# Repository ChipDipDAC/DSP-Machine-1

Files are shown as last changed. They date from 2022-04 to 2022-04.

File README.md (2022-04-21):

# DSP-Machine-1
Hi-Res Streamer - Power Amplifier for Raspberry Pi<br>
<a class="link" href="https://www.chipdip.ru/catalog-show/for-you-projects?p.0=ChipDipDac"><strong>DSP Machine 1</strong></a> - cтример, цифроаналоговый преобразователь ЦАП, аудиопроцессор, усилитель для микрокомпьютеров Raspberry Pi.<br />
Для построения стримера-усилителя вы можете использовать любой микрокомпьютер Raspberry Pi 2 или 3. Микрокомпьютер устанавливается на 40-пиновый разъем аудио карты. В качестве ПО используйте любой плеер или ОС образ, которых записан на микроSD карточку для Raspberry Pi. Операционные системы автоматически определяют аудиокарту ChipDip DAC и настраивают вывод звука именно на неё. В некоторых плеерах может понадобится выбрать в качестве устройства вывода звука - ChipDip DAC.<br />
<br />
- Plug and Play не требует пайки<br />
- Совместим с Raspberry Pi<br />
- Официальная поддержка RaspberryPi OS / Volumio3 / rAudio1 / Album Player / OpenELEC / Manjaro OS / MoOde и другими<br />
- DSP ADAU1701, чип усилителя TPA3255 для наилучшего качества звука.<br />
- Мощность 2х60 Вт<br />
- Разъемы аудиовыхода: две пары винтовых клемм (левый и правый)<br />
- Встроенная EEPROM для автоматической настройки ОС (с защитой от записи).<br />
- Автоматическое переключение частот в соответствии с входными сигналами I2S.<br />
- Диапазон частот дискретизации и разрядности от 44,1кГц/16 бит до 192кГц/32 бит<br />
- Совместим с ПО SigmaStudio и ChipStudio для перестройки аудиопроцессора<br />
<br />
Задать вопросы можно на форуме в разделе <a class="link" href="https://forum.chipdip.ru/index.php#chipdip-dac.39">ChipDip DAC</a>
<p><a class="galery" href="https://static.chipdip.ru/lib/992/DOC015992500.jpg">Pins DSP Machine1</a></p>

<p><a class="galery" href="https://static.chipdip.ru/lib/992/DOC015992501.jpg">Pins DSP Machine1</a></p>

<h2>Что под крышкой *</h2>

<p><a class="galery" href="https://static.chipdip.ru/lib/992/DOC015992815.jpg">Pins DSP Machine1</a></p>

<p><a class="galery" href="https://static.chipdip.ru/lib/992/DOC015992816.jpg">Pins DSP Machine1</a></p>
* Микрокомпьютер Raspberry Pi в комплект не входит.

<h2>Сравнительная таблица</h2>

<table class="user_t">
	<tbody>
		<tr>
			<td class="tcenter">&nbsp;</td>
			<td class="tcenter">DSP Machine 1</td>
			<td class="tcenter">DSP Machine 2</td>
			<td class="tcenter">DSP Machine 3</td>
		</tr>
		<tr>
			<td class="tcenter">Темброблок</td>
			<td class="tcenter">+</td>
			<td class="tcenter">+</td>
			<td class="tcenter">+</td>
		</tr>
		<tr>
			<td class="tcenter">SuperBass</td>
			<td class="tcenter">+</td>
			<td class="tcenter">+</td>
			<td class="tcenter">+</td>
		</tr>
		<tr>
			<td class="tcenter">Mute</td>
			<td class="tcenter">+</td>
			<td class="tcenter">+</td>
			<td class="tcenter">+</td>
		</tr>
		<tr>
			<td class="tcenter">Блок питания</td>
			<td class="tcenter">+</td>
			<td class="tcenter">+</td>
			<td class="tcenter">+</td>
		</tr>
		<tr>
			<td class="tcenter">Корректное выключение</td>
			<td class="tcenter">+</td>
			<td class="tcenter">+</td>
			<td class="tcenter">+</td>
		</tr>
		<tr>
			<td class="tcenter">Линейный выход</td>
			<td class="tcenter">-</td>
			<td class="tcenter">+</td>
			<td class="tcenter">+</td>
		</tr>
		<tr>
			<td class="tcenter">Усилитель мощности</td>
			<td class="tcenter">+</td>
			<td class="tcenter">-</td>
			<td class="tcenter">-</td>
		</tr>
		<tr>
			<td class="tcenter">Выход SPDIF</td>
			<td class="tcenter">-</td>
			<td class="tcenter">-</td>
			<td class="tcenter">+</td>
		</tr>
		<tr>
			<td class="tcenter">Выход Toslink</td>
			<td class="tcenter">-</td>
			<td class="tcenter">-</td>
			<td class="tcenter">+</td>
		</tr>
		<tr>
			<td class="tcenter">SigmaStudio</td>
			<td class="tcenter">+</td>
			<td class="tcenter">-</td>
			<td class="tcenter">+</td>
		</tr>
		<tr>
			<td class="tcenter">PurePathStudio</td>
			<td class="tcenter">-</td>
			<td class="tcenter">+</td>
			<td class="tcenter">-</td>
		</tr>
		<tr>
			<td class="tcenter">ChipStudio</td>
			<td class="tcenter">+</td>
			<td class="tcenter">+</td>
			<td class="tcenter">+</td>
		</tr>
	</tbody>
</table>
<br />

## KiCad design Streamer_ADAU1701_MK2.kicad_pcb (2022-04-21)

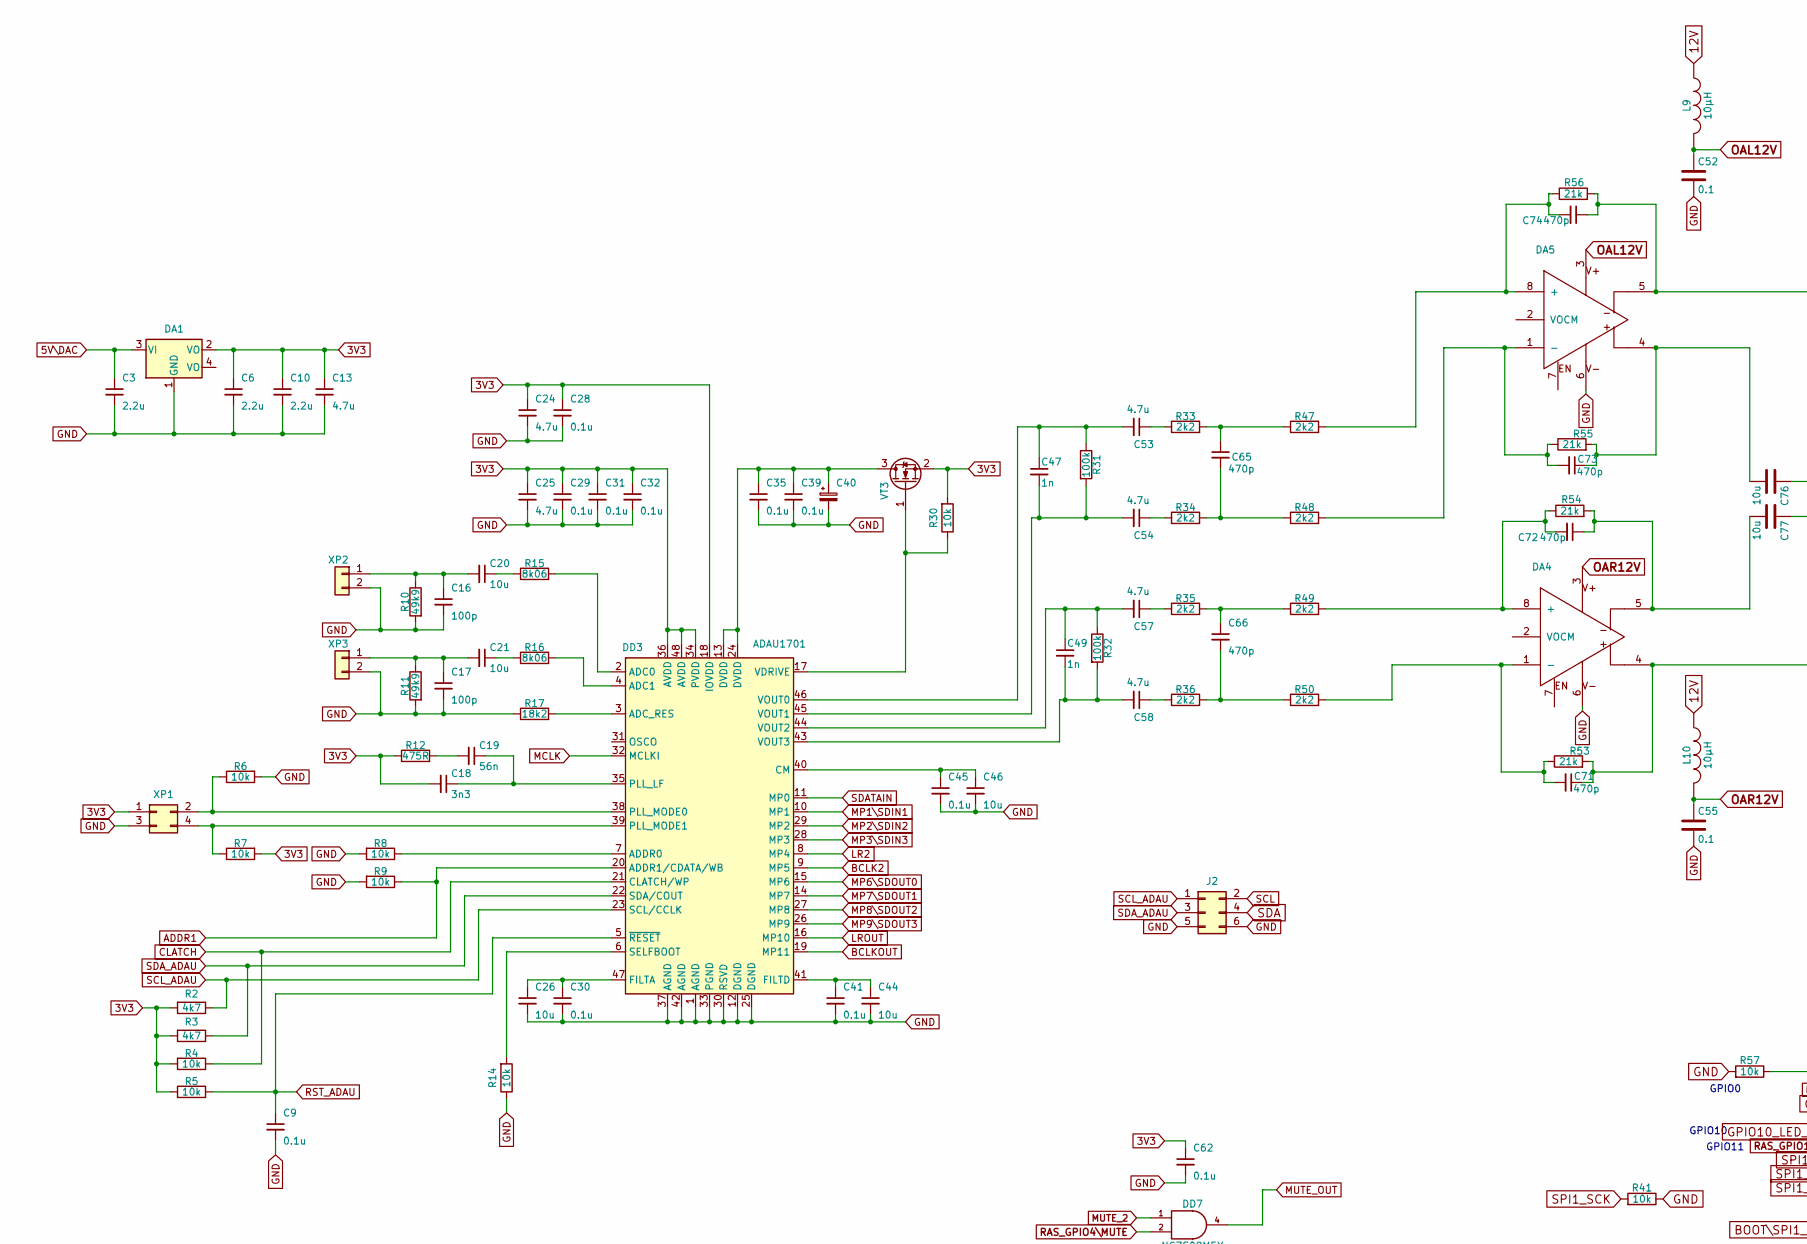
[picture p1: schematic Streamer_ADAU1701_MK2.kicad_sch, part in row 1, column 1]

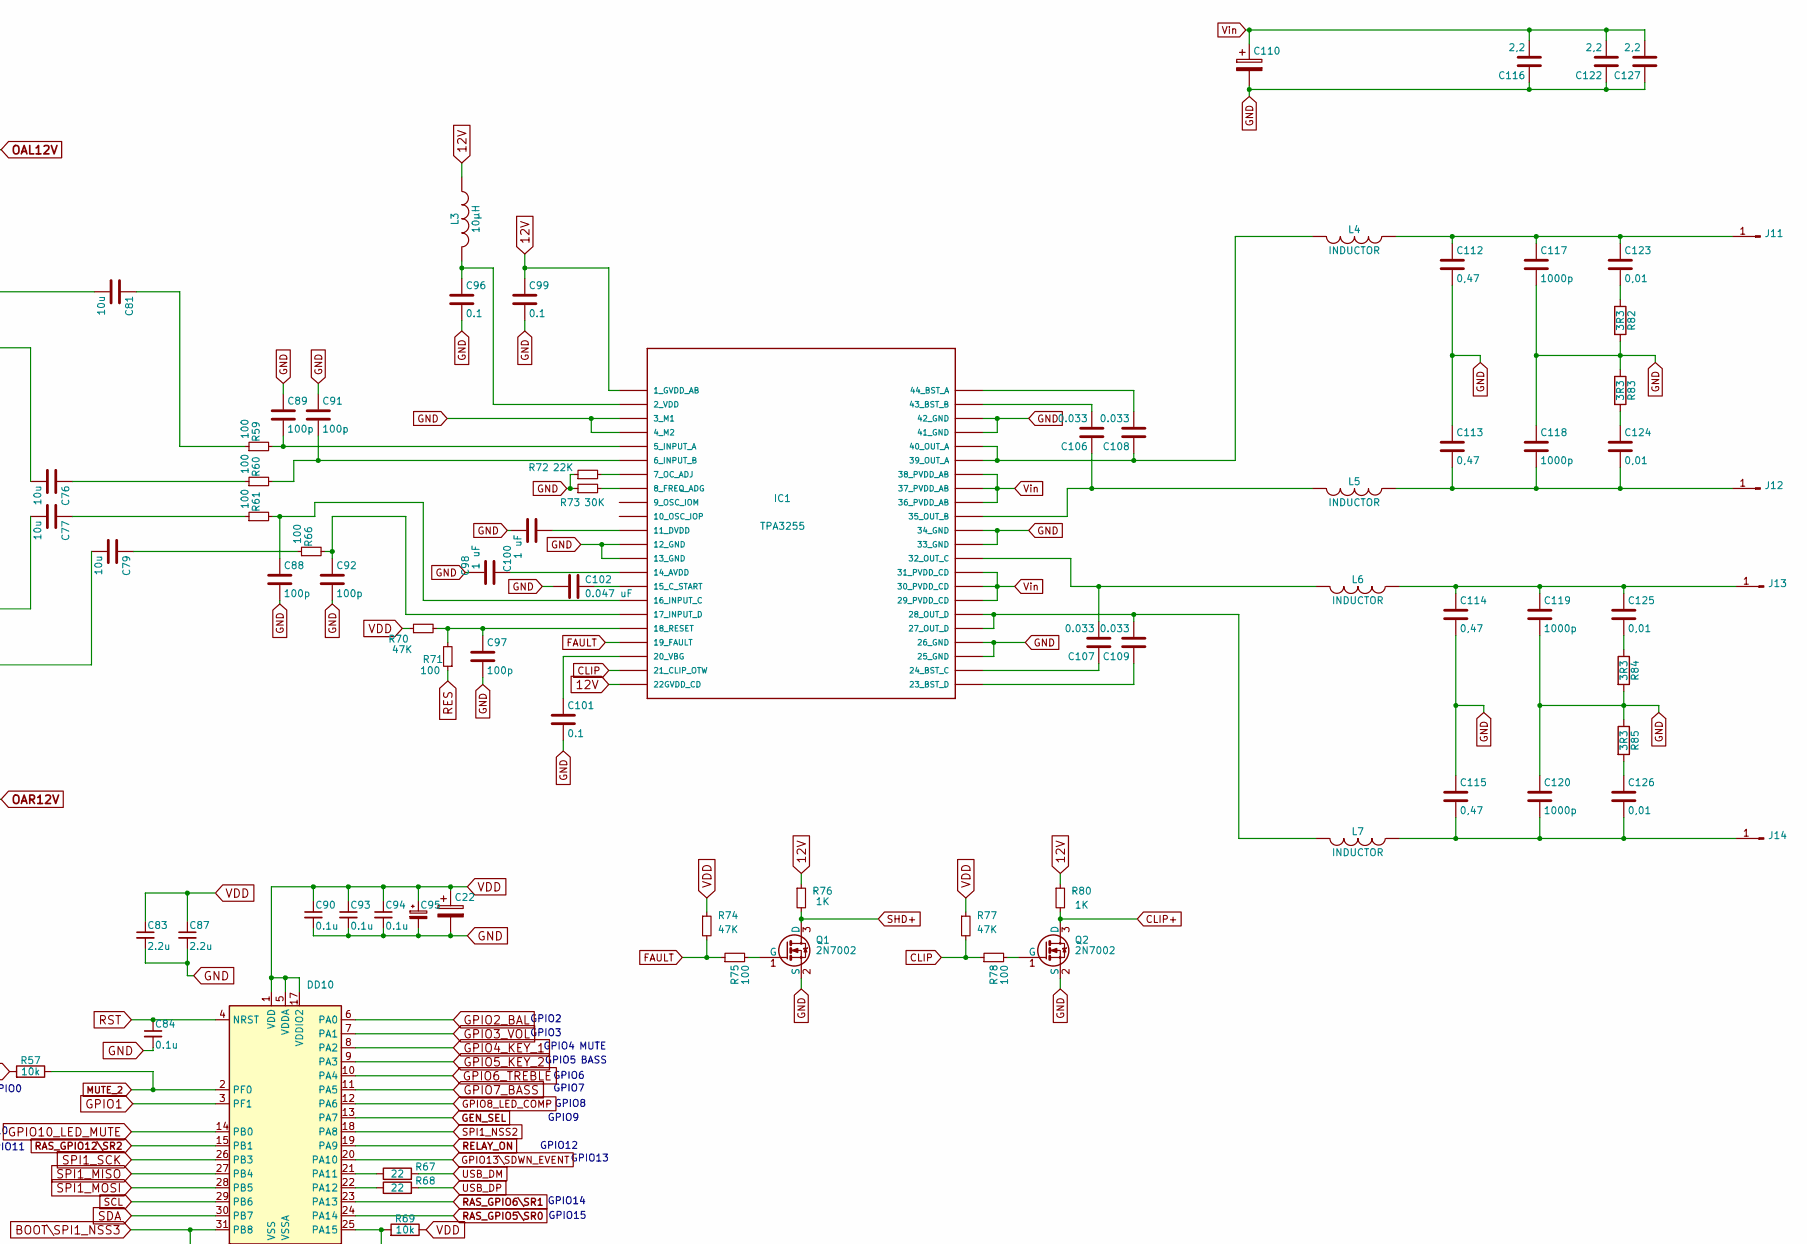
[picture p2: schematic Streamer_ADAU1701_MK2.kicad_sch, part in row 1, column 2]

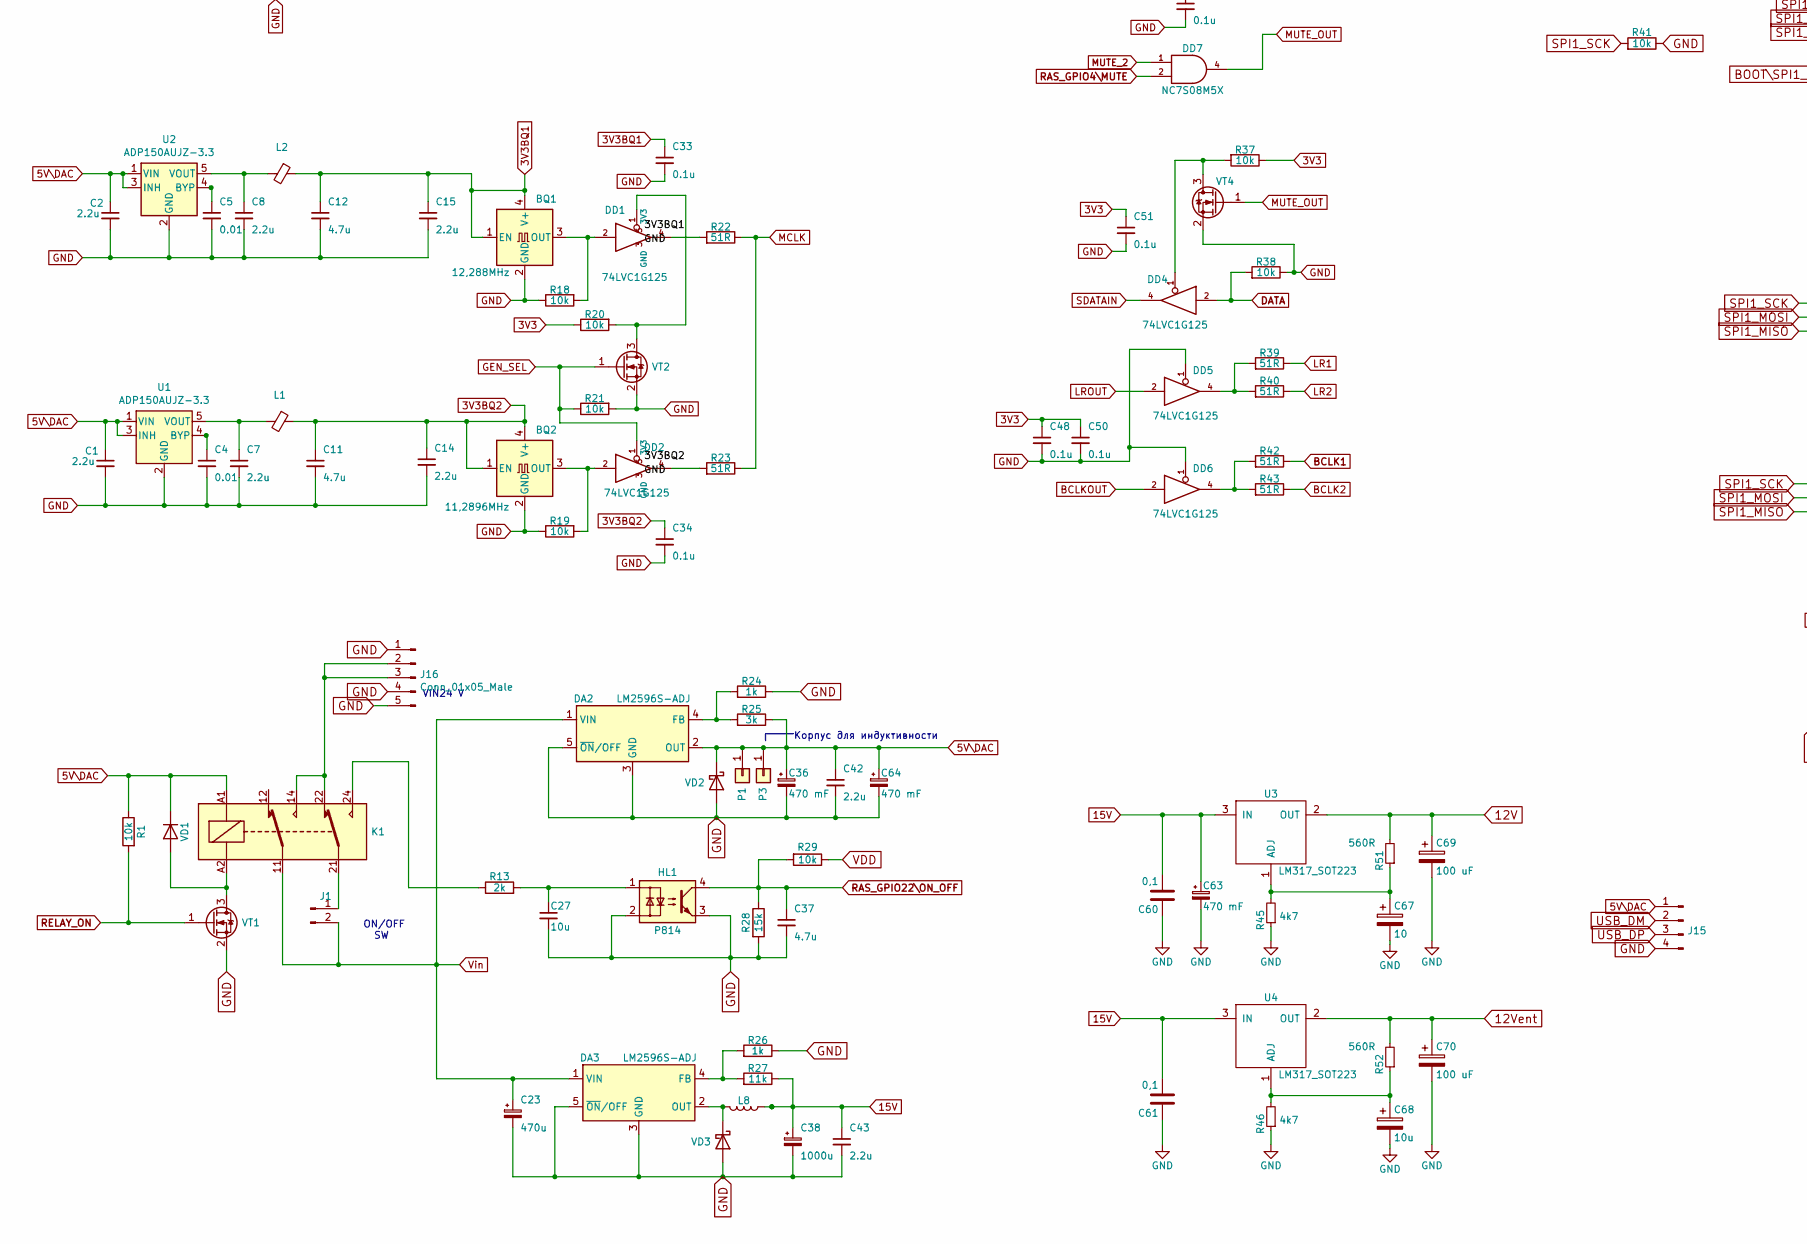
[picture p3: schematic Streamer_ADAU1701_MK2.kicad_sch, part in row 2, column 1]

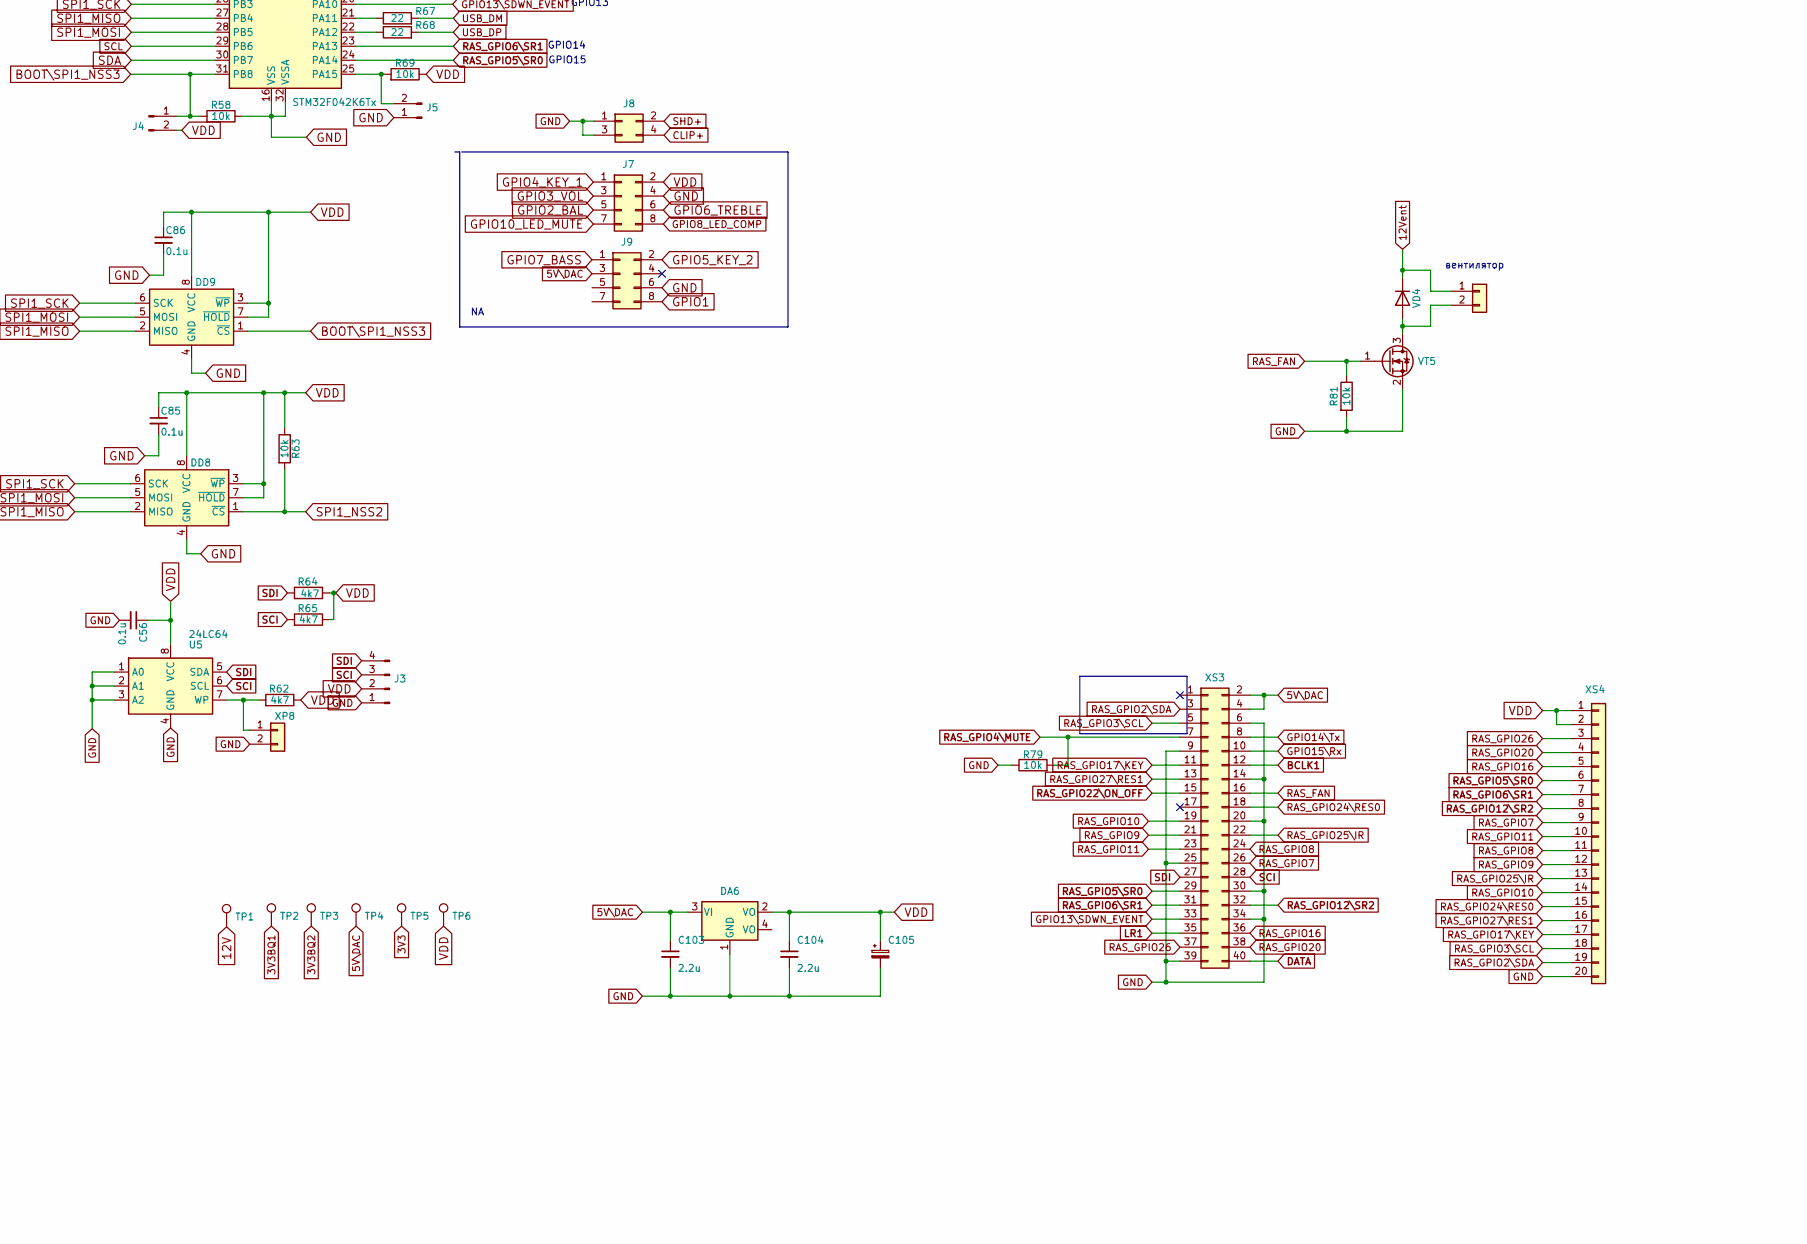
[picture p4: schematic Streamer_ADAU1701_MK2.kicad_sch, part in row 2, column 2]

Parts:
BQ1: 12,288MHz; Oscillator_SMD_Fordahl_DFAS2-4Pin_7.3x5.1mm_HandSoldering
BQ2: 11,2896MHz; Oscillator_SMD_Fordahl_DFAS2-4Pin_7.3x5.1mm_HandSoldering
C1, C2, C3, C6, C7, C8, C10, C14, C15, C42, C43, C83, C87, C103, C104: 2.2u; C_0603_1608Metric_Pad1.05x0.95mm_HandSolder
C4, C5: 0.01; C_0603_1608Metric_Pad1.05x0.95mm_HandSolder
C9, C29, C30, C31, C32, C33, C34, C35, C39, C41, C45, C48, C50, C51, C56, C62, C84, C85, C86, C90, C93, C94: 0.1u; C_0603_1608Metric_Pad1.05x0.95mm_HandSolder
C11, C12, C13, C24, C25, C37: 4.7u; CP_EIA-3216-18_Kemet-A_Pad1.58x1.35mm_HandSolder
C16, C17, C88, C89, C91, C92, C97: 100p; C_0603_1608Metric_Pad1.05x0.95mm_HandSolder
C18: 3n3; C_0603_1608Metric_Pad1.05x0.95mm_HandSolder
C19: 56n; C_0603_1608Metric_Pad1.05x0.95mm_HandSolder
C20, C21, C26, C27, C44, C46: 10u; C_0603_1608Metric_Pad1.05x0.95mm_HandSolder
C22, C40, C95, C105, C110: (no value)
C23: 470u; CP_Radial_D10.0mm_P5.00mm
C28: 0.1u; C_0805_2012Metric
C36, C63, C64: 470 mF; CP_Radial_D10.0mm_P5.00mm
C38: 1000u; CP_Radial_D10.0mm_P5.00mm
C47, C49: 1n; C_Disc_D4.7mm_W2.5mm_P5.00mm
C52, C55, C96, C99, C101: 0.1; C_0603_1608Metric_Pad1.05x0.95mm_HandSolder
C53, C54, C57, C58: 4.7u; CP_Radial_D5.0mm_P2.50mm
C60, C61: 0,1; C_0603_1608Metric_Pad1.05x0.95mm_HandSolder
C65, C66: 470p; C_Disc_D4.7mm_W2.5mm_P5.00mm
C67: 10; C_Radial_D5.0mm_H11.0mm_P2.00mm
C68, C76, C77, C79, C81: 10u; C_Radial_D5.0mm_H11.0mm_P2.00mm
C69: 100 uF; CP_Radial_D10.0mm_P5.00mm
C70: 100 uF; CP_Radial_D6.3mm_P2.50mm
C71, C72, C73, C74: 470p; C_0603_1608Metric_Pad1.05x0.95mm_HandSolder
C98, C100: 1 uF; C_0603_1608Metric_Pad1.05x0.95mm_HandSolder
C102: 0.047 uF; C_0603_1608Metric_Pad1.05x0.95mm_HandSolder
C106, C107, C108, C109: 0.033; C_0603_1608Metric_Pad1.05x0.95mm_HandSolder
C112, C113, C114, C115: 0,47; C_Rect_L7.2mm_W3.5mm_P5.00mm_FKS2_FKP2_MKS2_MKP2
C116, C122, C127: 2,2; C_1210_3225Metric_Pad1.42x2.65mm_HandSolder
C117, C118, C119, C120: 1000p; C_1206_3216Metric_Pad1.42x1.75mm_HandSolder
C123, C124, C125, C126: 0,01; C_0805_2012Metric_Pad1.15x1.40mm_HandSolder
DA1, DA6: LM1117-3.3; SOT-223
DA2, DA3: LM2596S-ADJ; TO-263-5_TabPin3
DA4, DA5: OPA1632-NewComponents_KiCad; MSOP-8-1EP_3x3mm_P0.65mm_EP1.95x2.15mm_ThermalVias
DD1, DD2, DD4, DD5, DD6: 74LVC1G125; SOT-23-5
DD3: ADAU1701; LQFP-48_7x7mm_P0.5mm
DD7: NC7S08M5X; SOT-23-5
DD8, DD9: 25LCxxx; SOIC-8_5.23x5.23mm_P1.27mm
DD10: STM32F042K6Tx; LQFP-32_7x7mm_P0.8mm
HL1: P814; DIP-4_W7.62mm
IC1: TPA3255; TSSOP-44_TPA255
J1, J4, J5: Conn_01x02_Male; PinHeader_1x02_P2.54mm_Vertical
J2: Conn_02x03_Odd_Even; PinHeader_2x03_P2.54mm_Vertical
J3, J15: Conn_01x04_Male; PinHeader_1x04_P2.54mm_Vertical
J7, J9: Conn_02x04_Odd_Even; PinHeader_2x04_P2.54mm_Vertical
J8: Conn_02x02_Odd_Even; PinHeader_2x02_P2.54mm_Vertical
J11, J12, J13, J14: Conn_01x01_Male; MountingHole_2.2mm_M2
J16: Conn_01x05_Male; BarrelJack_PD-40
K1: RTE2xxxx; Relay_DPDT_Schrack-RT2-FormC_RM5mm
L1, L2: (no value)
L3, L9, L10: 10μH; L_0603_1608Metric_Pad1.05x0.95mm_HandSolder
L4, L5, L6, L7: INDUCTOR; L_Toroid_Vertical_L21.6mm_W11.4mm_P7.62mm_Pulse_KM-3
L8: MMZ2012S601AT000; L_Radial_D7.8mm_P5.00mm_Fastron_07HCP
P1, P3: Conn_01x01; TestPoint_Keystone_5005-5009_Compact
Q1, Q2: 2N7002; TSOT-23
R1, R4, R5, R6, R7, R8, R9, R14, R18, R19, R20, R21, R29, R30, R37, R38, R57, R58, R63, R69, R79, R81: 10k; R_0603_1608Metric_Pad1.05x0.95mm_HandSolder
R2, R3, R45, R46, R62, R64, R65: 4k7; R_0603_1608Metric_Pad1.05x0.95mm_HandSolder
R10, R11: 49k9; R_0603_1608Metric_Pad1.05x0.95mm_HandSolder
R12: 475R; R_0603_1608Metric_Pad1.05x0.95mm_HandSolder
R13: 2k; R_0603_1608Metric_Pad1.05x0.95mm_HandSolder
R15, R16: 8k06; R_0603_1608Metric_Pad1.05x0.95mm_HandSolder
R17: 18k2; R_0603_1608Metric_Pad1.05x0.95mm_HandSolder
R22, R23, R39, R40, R42, R43: 51R; R_0603_1608Metric_Pad1.05x0.95mm_HandSolder
R24, R26: 1k; R_0603_1608Metric_Pad1.05x0.95mm_HandSolder
R25: 3k; R_0603_1608Metric_Pad1.05x0.95mm_HandSolder
R27: 11k; R_0603_1608Metric_Pad1.05x0.95mm_HandSolder
R28: 15k; R_0603_1608Metric_Pad1.05x0.95mm_HandSolder
R31, R32: 100k; R_0603_1608Metric_Pad1.05x0.95mm_HandSolder
R33, R34, R35, R36, R47, R48, R49, R50: 2k2; R_0603_1608Metric_Pad1.05x0.95mm_HandSolder
R41: 10k; R_0603_1608Metric_Pad0.98x0.95mm_HandSolder
R51, R52: 560R; R_0603_1608Metric_Pad1.05x0.95mm_HandSolder
R53, R54, R55, R56: 21k; R_Axial_DIN0204_L3.6mm_D1.6mm_P5.08mm_Horizontal
R59, R60, R61, R66, R71, R75, R78: 100; R_0603_1608Metric_Pad1.05x0.95mm_HandSolder
R67, R68: 22; R_0603_1608Metric_Pad1.05x0.95mm_HandSolder
R70, R74, R77: 47K; R_0603_1608Metric_Pad1.05x0.95mm_HandSolder
R72: 22K; R_0603_1608Metric_Pad1.05x0.95mm_HandSolder
R73: 30K; R_0603_1608Metric_Pad1.05x0.95mm_HandSolder
R76, R80: 1K; R_0603_1608Metric_Pad1.05x0.95mm_HandSolder
R82, R83, R84, R85: 3R3; R_0805_2012Metric_Pad1.15x1.40mm_HandSolder
TP1, TP2, TP3, TP4, TP5, TP6: TestPoint; TestPoint_Pad_D1.5mm
U1, U2: ADP150AUJZ-3.3; SOT-23-5
U3, U4: LM317_SOT223; SOT-223
U5: 24LC64; SOIC-8_3.9x4.9mm_P1.27mm
VD1, VD4: D; D_SOD-123
VD2, VD3: D_Schottky; D_SMC_Handsoldering
VT1, VT2, VT3, VT4, VT5: BSS138; SOT-23
XP1: Conn_02x02_Odd_Even; PinHeader_2x02_P2.54mm_Vertical
XP2, XP3, XP8, XP9: Conn_01x02; PinHeader_1x02_P2.54mm_Vertical
XS3: Conn_02x20_Odd_Even; PinSocket_2x20_P2.54mm_Vertical
XS4: Conn_01x20; Hirose_FH12-20S-0.5SH_1x20-1MP_P0.50mm_Horizontal

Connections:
3V3: C6.1, C10.1, C13.1, C18.2, C24.1, C25.1, C28.1, C29.1, C31.1, C32.1, C48.1, C50.1, C51.1, C62.1, DA1.2 (VO), DD3.18 (IOVDD), DD3.34 (PVDD), DD3.36 (AVDD), DD3.48 (AVDD), DD4.5 (3V3), DD5.5 (3V3), DD6.5 (3V3), DD7.5 (3V3), R2.2, R3.2, R4.2, R5.2, R7.2, R12.1, R20.1, R30.2, R37.1, TP5.1, VT3.2 (S), XP1.1
3V3BQ1: BQ1.1 (EN), BQ1.4 (V+), C12.1, C15.1, C33.1, DD1.5 (3V3), L2.1, TP2.1
3V3BQ2: BQ2.1 (EN), BQ2.4 (V+), C11.1, C14.1, C34.1, DD2.5 (3V3), L1.1, TP3.1
5V\DAC: C1.1, C2.1, C3.1, C36.1, C42.1, C64.1, C103.1, DA1.3 (VI), DA2.2 (OUT), DA6.3 (VI), J9.3, J15.1, K1.A1, P1.1, P3.1, R1.1, R25.1, TP4.1, U1.1 (VIN), U1.3 (INH), U2.1 (VIN), U2.3 (INH), VD1.1 (K), VD2.1 (K), XS3.2, XS3.4
12V: C69.1, C99.1, IC1.1 (1_GVDD_AB), IC1.22 (22GVDD_CD), L3.1, L9.1, L10.1, R51.2, R76.1, R80.1, TP1.1, U3.2 (OUT)
12Vent: C70.1, R52.2, U4.2 (OUT), VD4.1 (K), XP9.1
15V: C38.1, C43.1, C60.2, C61.2, C63.1, L8.1, R27.1, U3.3 (IN), U4.3 (IN); also elsewhere on the board
ADDR1: DD3.20 (ADDR1/CDATA/WB), R9.1
BCLK1: R42.1, XS3.12
BCLK2: DD3.9 (MP5), R43.1
BCLKOUT: DD3.19 (MP11), DD6.2
BOOT\SPI1_NSS3: DD9.1 (~CS), DD10.31 (PB8), J4.1, R58.2
CLATCH: DD3.21 (CLATCH/WP), R4.1
CLIP: IC1.21 (21_CLIP_OTW), R77.2, R78.1
CLIP+: J8.4, Q2.3 (D), R80.2
DATA: DD4.2, R38.2, XS3.40
FAULT: IC1.19 (19_FAULT), R74.2, R75.1
GEN_SEL: DD2.1, DD10.13 (PA7), R21.1, VT2.1 (G)
GND: BQ1.2 (GND), BQ2.2 (GND), C1.2, C2.2, C3.2, C4.2, C5.2, C6.2, C7.2, C8.2, C9.2, C10.2, C11.2, C12.2, C13.2, C14.2, C15.2, C16.2, C17.2, C22.2, C23.2, C24.2, C25.2, C26.2, C27.2, C28.2, C29.2, C30.2, C31.2, C32.2, C33.2, C34.2, C35.2, C36.2, C37.2, C38.2, C39.2, C40.2, C41.2, C42.2, C43.2, C44.2, C45.2, C46.2, C48.2, C50.2, C51.2, C52.2, C55.2, C56.2, C60.1, C61.1, C62.2, C63.2, C64.2, C67.2, C68.2, C69.2, C70.2, C83.2, C84.2, C85.2, C86.2, C87.2, C88.2, C89.1, C90.2, C91.1, C92.2, C93.2, C94.2, C95.2, C96.2, C97.2, C98.2, C99.2, C100.2, C101.2, C102.2, C103.2, C104.2, C105.2, C110.2, C112.2, C113.1, C114.2, C115.1, C116.1, C117.2, C118.1, C119.2, C120.1, C122.1, C127.1, DA1.1 (GND), DA2.3 (GND), DA2.5 (~ON/OFF), DA3.3 (GND), DA3.5 (~ON/OFF), DA4.6, DA5.6, DA6.1 (GND), DD1.3 (GND), DD2.3 (GND), DD3.1 (AGND), DD3.12 (DGND), DD3.25 (DGND), DD3.30 (RSVD), DD3.33 (PGND), DD3.37 (AGND), DD3.42 (AGND), DD4.3 (GND), DD5.1, DD5.3 (GND), DD6.1, DD6.3 (GND), DD7.3 (GND), DD8.4 (GND), DD9.4 (GND), DD10.16 (VSS), DD10.32 (VSSA), HL1.2, HL1.3, IC1.3 (3_M1), IC1.4 (4_M2), IC1.12 (12_GND), IC1.13 (13_GND), IC1.25 (25_GND), IC1.26 (26_GND), IC1.33 (33_GND), IC1.34 (34_GND), IC1.41 (41_GND), IC1.42 (42_GND), J2.5, J2.6, J3.1, J5.1, J7.4, J8.1, J8.3, J9.6, J15.4, J16.1, J16.4, J16.5, Q1.2 (S), Q2.2 (S), R6.2, R8.2, R9.2, R10.2, R11.2, R14.1, R17.1, R18.1, R19.1, R21.2, R24.1, R26.1, R28.2, R38.1, R41.1, R45.1, R46.1, R57.2, R58.1, R72.1, R73.1, R79.1, R81.2, R82.2, R83.1, R84.2, R85.1, U1.2 (GND), U2.2 (GND), U5.1 (A0), U5.2 (A1), U5.3 (A2), U5.4 (GND), VD2.2 (A), VD3.2 (A), VT1.2 (S), VT2.2 (S), VT4.2 (S), VT5.2 (S), XP1.3, XP2.2, XP3.2, XP8.2, XS3.6, XS3.9, XS3.14, XS3.20, XS3.25, XS3.30, XS3.34, XS3.39, XS4.20
GPIO1: DD10.3 (PF1), J9.8
GPIO2_BAL: DD10.6 (PA0), J7.5
GPIO3_VOL: DD10.7 (PA1), J7.3
GPIO4_KEY_1: DD10.8 (PA2), J7.1
GPIO5_KEY_2: DD10.9 (PA3), J9.2
GPIO6_TREBLE: DD10.10 (PA4), J7.6
GPIO7_BASS: DD10.11 (PA5), J9.1
GPIO8_LED_COMP: DD10.12 (PA6), J7.8
GPIO10_LED_MUTE: DD10.14 (PB0), J7.7
GPIO13\SDWN_EVENT: DD10.20 (PA10), XS3.33
GPIO14\Tx: XS3.8
GPIO15\Rx: XS3.10
LR1: R39.1, XS3.35
LR2: DD3.8 (MP4), R40.1
LROUT: DD3.16 (MP10), DD5.2
MCLK: DD3.32 (MCLKI), R22.1, R23.1
MP1\SDIN1: DD3.10 (MP1)
MP2\SDIN2: DD3.29 (MP2)
MP3\SDIN3: DD3.28 (MP3)
MP6\SDOUT0: DD3.15 (MP6)
MP7\SDOUT1: DD3.14 (MP7)
MP8\SDOUT2: DD3.27 (MP8)
MP9\SDOUT3: DD3.26 (MP9)
MUTE_2: DD7.1, DD10.2 (PF0), R57.1
MUTE_OUT: DD7.4, VT4.1 (G)
unnamed: BQ1.3 (OUT), DD1.2, R18.2
unnamed: BQ2.3 (OUT), DD2.2, R19.2
unnamed: C4.1, U1.4 (BYP)
unnamed: C5.1, U2.4 (BYP)
unnamed: C7.1, L1.2, U1.5 (VOUT)
unnamed: C8.1, L2.2, U2.5 (VOUT)
unnamed: C16.1, C20.2, R10.1, XP2.1
unnamed: C17.1, C21.2, R11.1, XP3.1
unnamed: C18.1, C19.1, DD3.35 (PLL_LF)
unnamed: C19.2, R12.2
unnamed: C20.1, R15.1
unnamed: C21.1, R16.1
unnamed: C26.1, C30.1, DD3.47 (FILTA)
unnamed: C27.1, HL1.1, R13.2
unnamed: C35.1, C39.1, C40.1, DD3.13 (DVDD), DD3.24 (DVDD), VT3.3 (D)
unnamed: C41.1, C44.1, DD3.41 (FILTD)
unnamed: C45.1, C46.1, DD3.40 (CM)
unnamed: C47.1, C53.2, DD3.46 (VOUT0), R31.1
unnamed: C47.2, C54.2, DD3.45 (VOUT1), R31.2
unnamed: C49.1, C57.2, DD3.44 (VOUT2), R32.1
unnamed: C49.2, C58.2, DD3.43 (VOUT3), R32.2
unnamed: C53.1, R33.1
unnamed: C54.1, R34.1
unnamed: C57.1, R35.1
unnamed: C58.1, R36.1
unnamed: C65.1, R33.2, R47.1
unnamed: C65.2, R34.2, R48.1
unnamed: C66.1, R35.2, R49.1
unnamed: C66.2, R36.2, R50.1
unnamed: C67.1, R45.2, R51.1, U3.1 (ADJ)
unnamed: C68.1, R46.2, R52.1, U4.1 (ADJ)
unnamed: C71.1, C79.2, DA4.4, R53.2
unnamed: C71.2, DA4.1 (-), R50.2, R53.1
unnamed: C72.1, C77.2, DA4.5, R54.2
unnamed: C72.2, DA4.8 (+), R49.2, R54.1
unnamed: C73.1, C76.2, DA5.4, R55.2
unnamed: C73.2, DA5.1 (-), R48.2, R55.1
unnamed: C74.1, C81.2, DA5.5, R56.2
unnamed: C74.2, DA5.8 (+), R47.2, R56.1
unnamed: C76.1, R60.1
unnamed: C77.1, R61.1
unnamed: C79.1, R66.1
unnamed: C81.1, R59.1
unnamed: C88.1, IC1.16 (16_INPUT_C), R61.2
unnamed: C89.2, IC1.5 (5_INPUT_A), R59.2
unnamed: C91.2, IC1.6 (6_INPUT_B), R60.2
unnamed: C92.1, IC1.17 (17_INPUT_D), R66.2
unnamed: C96.1, IC1.2 (2_VDD), L3.2
unnamed: C97.1, IC1.18 (18_RESET), R70.2, R71.2
unnamed: C98.1, IC1.14 (14_AVDD)
unnamed: C100.1, IC1.11 (11_DVDD)
unnamed: C101.1, IC1.20 (20_VBG)
unnamed: C102.1, IC1.15 (15_C_START)
unnamed 97: C106.1, IC1.35 (35_OUT_B), L5.2; also elsewhere on the board
unnamed: C106.2, IC1.43 (43_BST_B)
unnamed: C107.1, IC1.24 (24_BST_C)
unnamed 100: C107.2, IC1.32 (32_OUT_C), L6.2; also elsewhere on the board
unnamed 101: C108.1, IC1.39 (39_OUT_A), IC1.40 (40_OUT_A), L4.2; also elsewhere on the board
unnamed: C108.2, IC1.44 (44_BST_A)
unnamed: C109.1, IC1.23 (23_BST_D)
unnamed 104: C109.2, IC1.27 (27_OUT_D), IC1.28 (28_OUT_D), L7.2; also elsewhere on the board
unnamed 105: C112.1, C117.1, C123.1, J11.1, J11.J11, L4.1; also elsewhere on the board
unnamed 106: C113.2, C118.2, C124.2, J12.1, L5.1; also elsewhere on the board
unnamed 107: C114.1, C119.1, C125.1, J13.1, L6.1; also elsewhere on the board
unnamed 108: C115.2, C120.2, C126.2, J14.1, L7.1; also elsewhere on the board
unnamed: C123.2, R82.1
unnamed: C124.1, R83.2
unnamed: C125.2, R84.1
unnamed: C126.1, R85.2
unnamed: DA2.4 (FB), R24.2, R25.2
unnamed: DA3.4 (FB), R26.2, R27.2
unnamed: DD1.1, R20.2, VT2.3 (D)
unnamed: DD1.4, R22.2
unnamed: DD2.4, R23.2
unnamed: DD3.2 (ADC0), R15.2
unnamed: DD3.3 (ADC_RES), R17.2
unnamed: DD3.4 (ADC1), R16.2
unnamed: DD3.6 (SELFBOOT), R14.2
unnamed: DD3.7 (ADDR0), R8.1
unnamed: DD3.17 (VDRIVE), R30.1, VT3.1 (G)
unnamed: DD3.38 (PLL_MODE0), R6.1, XP1.2
unnamed: DD3.39 (PLL_MODE1), R7.1, XP1.4
unnamed: DD4.1, R37.2, VT4.3 (D)
unnamed: DD5.4, R39.2, R40.2
unnamed: DD6.4, R42.2, R43.2
unnamed: DD10.21 (PA11), R67.1
unnamed: DD10.22 (PA12), R68.1
unnamed: DD10.25 (PA15), J5.2, R69.2
unnamed: IC1.7 (7_OC_ADJ), R72.2
unnamed: IC1.8 (8_FREQ_ADG), R73.2
unnamed: J1.1, K1.21
unnamed: J16.2, J16.3, K1.14, K1.22
unnamed: K1.24, R13.1
unnamed: K1.A2, VD1.2 (A), VT1.3 (D)
unnamed: Q1.1 (G), R75.2
unnamed: Q2.1 (G), R78.2
unnamed: R62.2, U5.7 (WP), XP8.1
unnamed: VD4.2 (A), VT5.3 (D), XP9.2
OAL12V: C52.1, DA5.3, L9.2
OAR12V: C55.1, DA4.3, L10.2
RAS_FAN: R81.1, VT5.1 (G), XS3.16
RAS_GPIO2\SDA: XS3.3, XS4.19
RAS_GPIO3\SCL: XS3.5, XS4.18
RAS_GPIO4\MUTE: DD7.2, R79.2, XS3.7
RAS_GPIO5\SR0: DD10.24 (PA14), XS3.29, XS4.6
RAS_GPIO6\SR1: DD10.23 (PA13), XS3.31, XS4.7
RAS_GPIO7: XS3.26, XS4.9
RAS_GPIO8: XS3.24, XS4.11
RAS_GPIO9: XS3.21, XS4.12
RAS_GPIO10: XS3.19, XS4.14
RAS_GPIO11: XS3.23, XS4.10
RAS_GPIO12\SR2: DD10.15 (PB1), XS3.32, XS4.8
RAS_GPIO16: XS3.36, XS4.5
RAS_GPIO17\KEY: XS3.11, XS4.17
RAS_GPIO20: XS3.38, XS4.4
RAS_GPIO22\ON_OFF: C37.1, HL1.4, R28.1, R29.2, XS3.15
RAS_GPIO24\RES0: XS3.18, XS4.15
RAS_GPIO25\IR: XS3.22, XS4.13
RAS_GPIO26: XS3.37, XS4.3
RAS_GPIO27\RES1: XS3.13, XS4.16
RELAY_ON: DD10.19 (PA9), R1.2, VT1.1 (G)
RES: R71.1
RST: C84.1, DD10.4 (NRST)
RST_ADAU: C9.1, DD3.5 (~RESET), R5.1
SCI: J3.3, R65.2, U5.6 (SCL), XS3.28
SCL: DD10.29 (PB6), J2.2
SCL_ADAU: DD3.23 (SCL/CCLK), J2.1, R2.1
SDA: DD10.30 (PB7), J2.4
SDATAIN: DD3.11 (MP0), DD4.4
SDA_ADAU: DD3.22 (SDA/COUT), J2.3, R3.1
SDI: J3.4, R64.2, U5.5 (SDA), XS3.27
SHD+: J8.2, Q1.3 (D), R76.2
SPI1_MISO: DD8.2 (MISO), DD9.2 (MISO), DD10.27 (PB4)
SPI1_MOSI: DD8.5 (MOSI), DD9.5 (MOSI), DD10.28 (PB5)
SPI1_NSS2: DD8.1 (~CS), DD10.18 (PA8), R63.2
SPI1_SCK: DD8.6 (SCK), DD9.6 (SCK), DD10.26 (PB3), R41.2
USB_DM: J15.2, R67.2
USB_DP: J15.3, R68.2
VDD: C22.1, C56.1, C83.1, C85.1, C86.1, C87.1, C90.1, C93.1, C94.1, C95.1, C104.1, C105.1, DA6.2 (VO), DD8.3 (~WP), DD8.7 (~HOLD), DD8.8 (VCC), DD9.3 (~WP), DD9.7 (~HOLD), DD9.8 (VCC), DD10.1 (VDD), DD10.5 (VDDA), DD10.17 (VDDIO2), J3.2, J4.2, J7.2, R29.1, R62.1, R63.1, R64.1, R65.1, R69.1, R70.1, R74.1, R77.1, TP6.1, U5.8 (VCC), XS4.1, XS4.2
Vin: C23.1, C110.1, C116.2, C122.2, C127.2, DA2.1 (VIN), DA3.1 (VIN), IC1.29 (29_PVDD_CD), IC1.30 (30_PVDD_CD), IC1.31 (31_PVDD_CD), IC1.36 (36_PVDD_AB), IC1.37 (37_PVDD_AB), IC1.38 (38_PVDD_AB), J1.2, K1.11

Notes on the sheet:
вентилятор
Корпус для индуктивности
GPIO9
GPIO0
GPIO12
BASS
GPIO2
GPIO15
GPIO14
MUTE
GPIO11
GPIO3
GPIO4
GPIO10
GPIO13
GPIO8
GPIO7
GPIO5
GPIO6
VIN24 V
ON/OFF SW

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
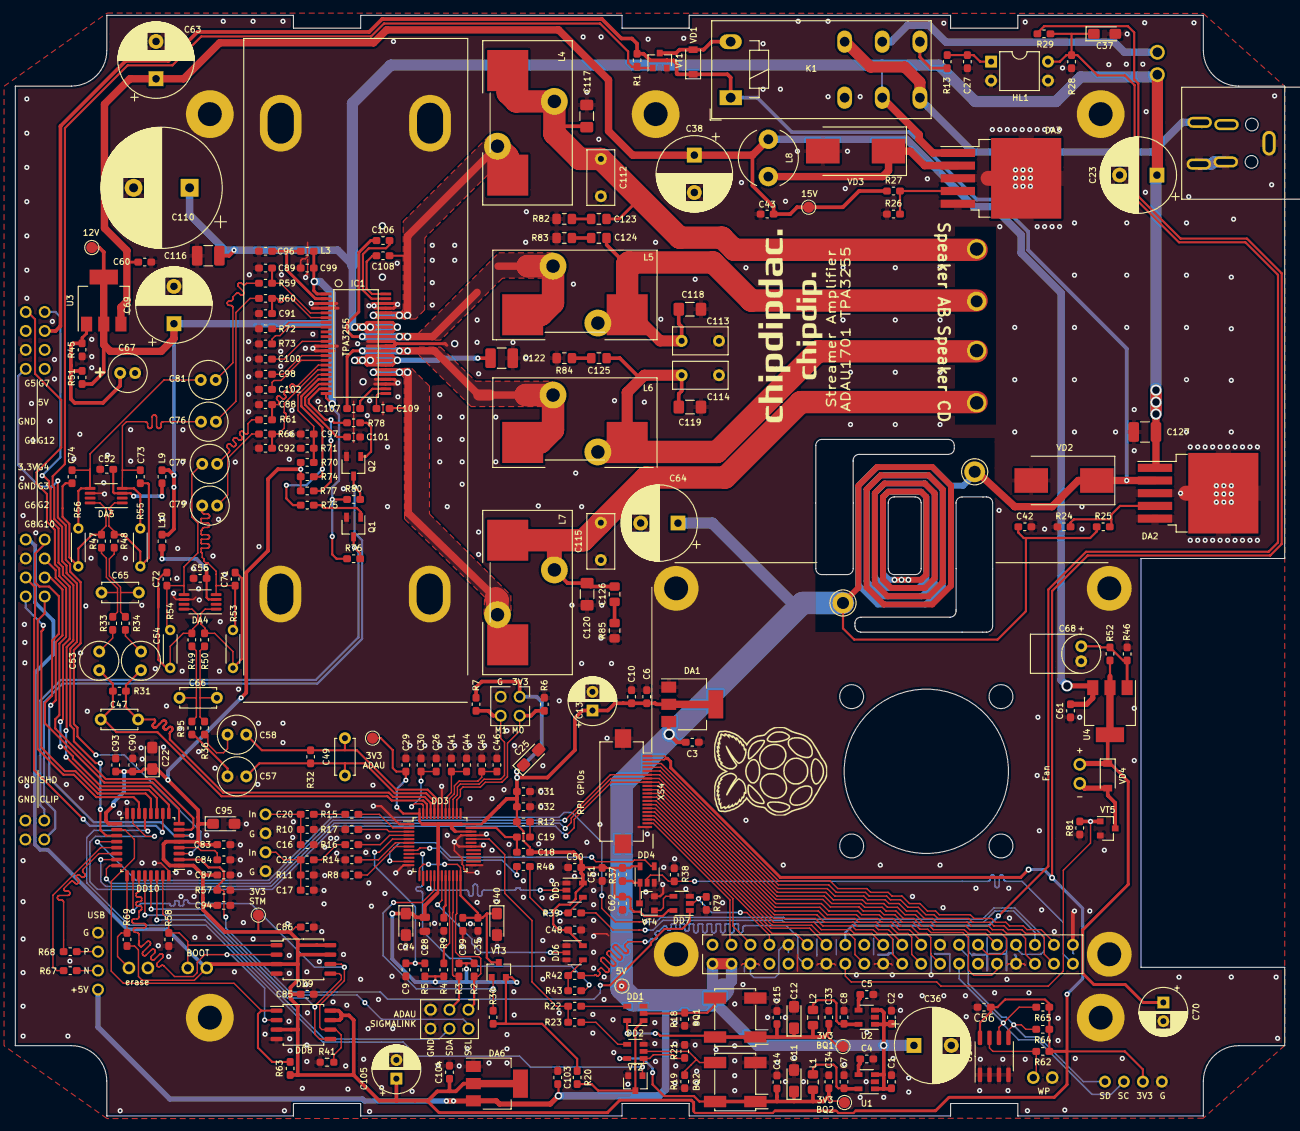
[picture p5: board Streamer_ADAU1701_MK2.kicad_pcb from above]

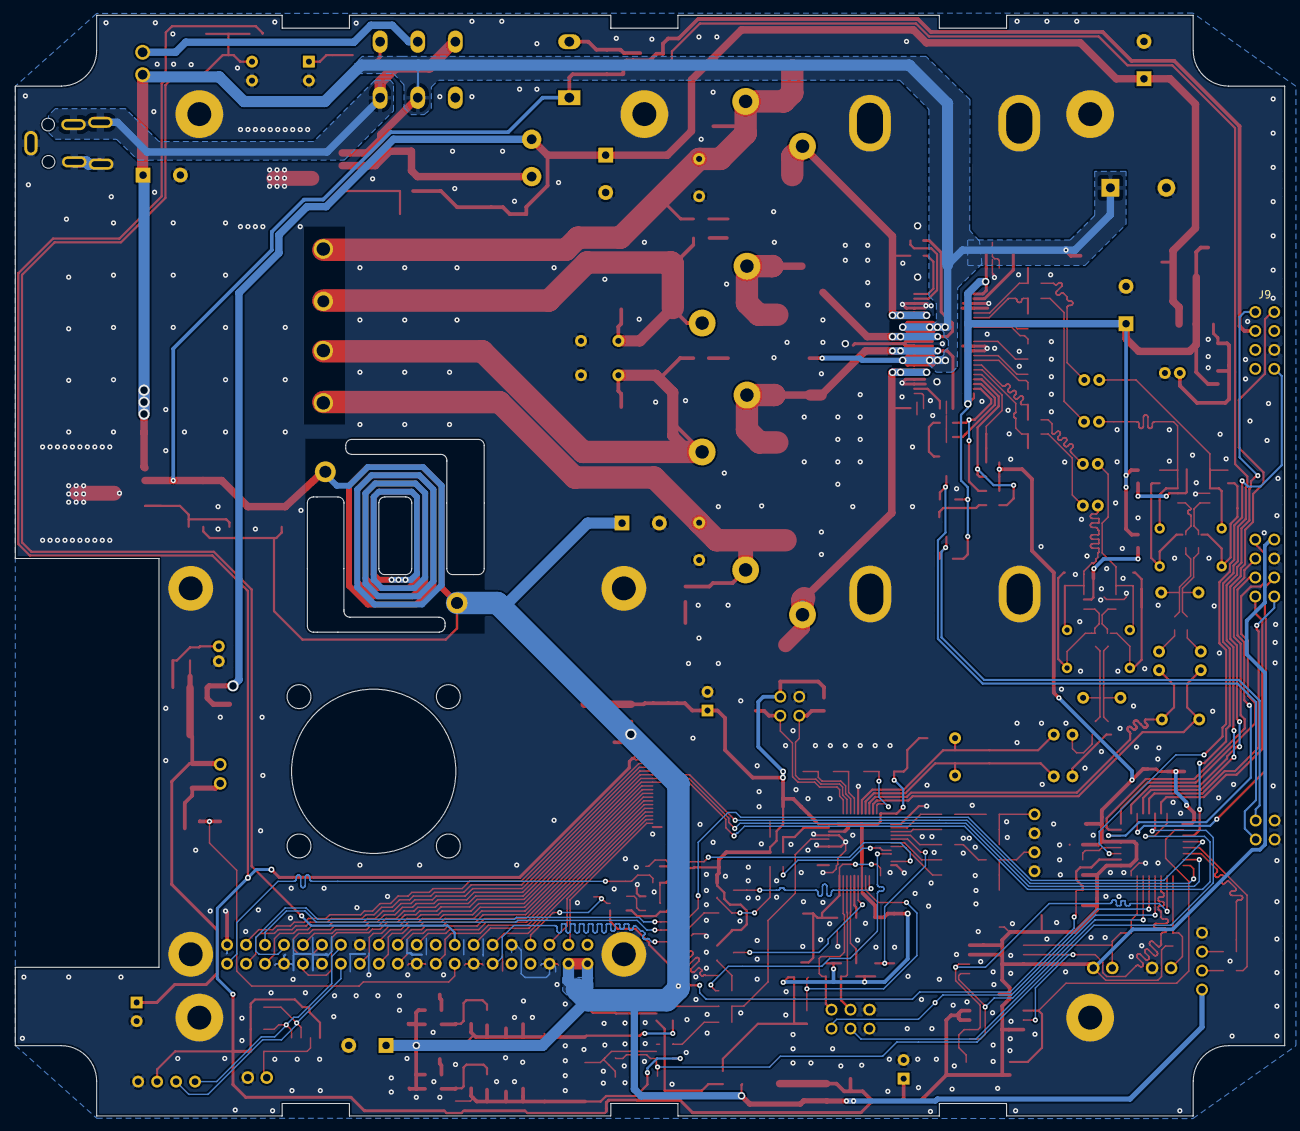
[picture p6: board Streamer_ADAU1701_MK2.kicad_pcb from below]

Board: 4 copper layers, 170.0 x 147.4 mm, 285 parts (2 on the bottom side), 175 nets.

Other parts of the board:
L3#2, L3#3, L3#4, L3#5: INDUCTOR; L_0029v2
TP4#2: TestPoint; TestPoint_Pad_D1.5mm

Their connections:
15V: TP4#2.1; also elsewhere on the board
unnamed 97: L3#4.1; also elsewhere on the board
unnamed 100: L3#5.1; also elsewhere on the board
unnamed 101: L3#2.2; also elsewhere on the board
unnamed 104: L3#3.2; also elsewhere on the board
unnamed 105: L3#2.1; also elsewhere on the board
unnamed 106: L3#4.2; also elsewhere on the board
unnamed 107: L3#5.2; also elsewhere on the board
unnamed 108: L3#3.1; also elsewhere on the board

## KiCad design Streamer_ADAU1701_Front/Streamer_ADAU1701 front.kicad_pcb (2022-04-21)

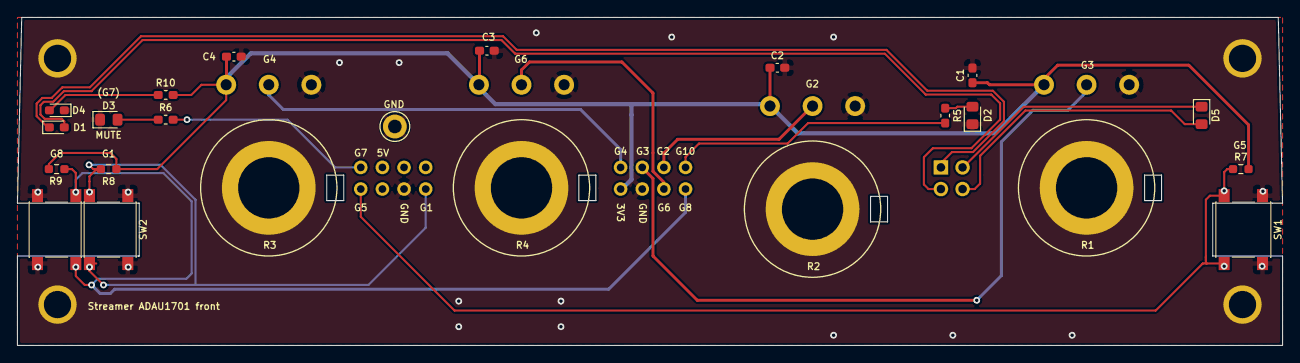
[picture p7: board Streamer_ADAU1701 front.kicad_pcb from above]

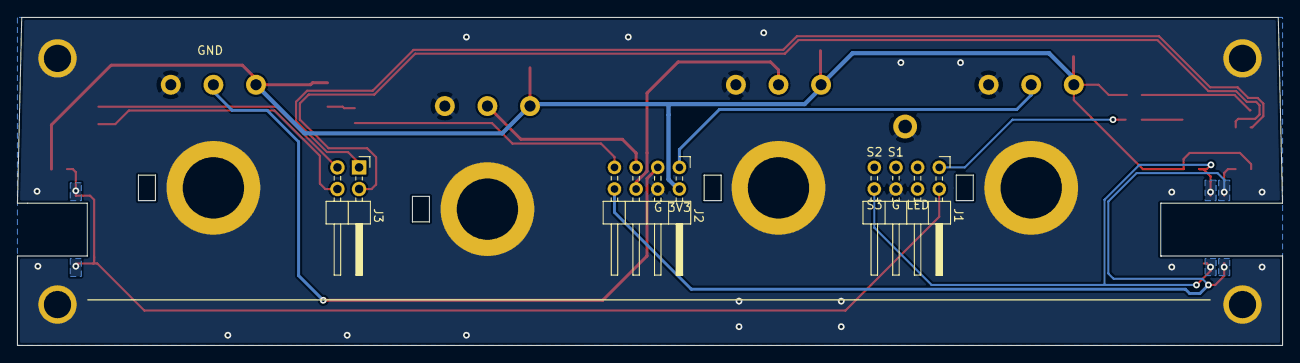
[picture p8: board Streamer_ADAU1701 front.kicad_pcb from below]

Board: 2 copper layers, 148.5 x 38.5 mm, 25 parts (3 on the bottom side), 18 nets.

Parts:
C1, C2, C3, C4: 0.1; C_0603_1608Metric_Pad1.08x0.95mm_HandSolder
D1, D4: LED; LED_0603_1608Metric_Pad1.05x0.95mm_HandSolder
D2, D3, D5: LED; LED_0805_2012Metric_Pad1.15x1.40mm_HandSolder
J1, J2: Conn_02x04_Odd_Even; PinHeader_2x04_P2.54mm_Horizontal
J3: Conn_02x02_Odd_Even; PinHeader_2x02_P2.54mm_Horizontal
R1, R2, R3, R4: R_POT_TRIM; Potentiometer_Piher_PC-16_Single_Vertical
R5, R6, R10: 560R; R_0603_1608Metric_Pad1.05x0.95mm_HandSolder
R7, R8, R9: 10k; R_0603_1608Metric_Pad0.98x0.95mm_HandSolder
SW1, SW2, SW3: SW_Push_Dual; SW_SPST_PTS645

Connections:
CLIP+: D5.2, J3.4
CLIP-: D5.1, J3.3
GND: C1.2, C2.2, C3.2, C4.2, D2.1, D3.1, D4.1, J1.6, J2.4, R1.3, R2.3, R3.3, R4.3, SW1.1, SW2.1, SW3.1
GPIO1_COMP: J1.8, R8.2, SW2.2
GPIO2_BAL: J2.5, R2.2
GPIO3_VOL: J2.3, R1.2
GPIO4_BASS: J2.1, R3.2
GPIO5_MUTE: J1.2, R7.1, SW1.2
GPIO6_TREBLE: J2.6, R4.2
GPIO7\LED_COMP: J1.1, R6.2
GPIO8_SBASS: J2.8, R9.2, SW3.2
GPIO10\LED_MUTE: J2.7, R5.2
unnamed: D2.2, R5.1
unnamed: D3.2, R6.1
unnamed: D4.2, R10.1
SHD+: D1.2, J3.2
SHD-: D1.1, J3.1
VDD: C1.1, C2.1, C3.1, C4.1, J2.2, R1.1, R2.1, R3.1, R4.1, R7.2, R8.1, R9.1, R10.2
